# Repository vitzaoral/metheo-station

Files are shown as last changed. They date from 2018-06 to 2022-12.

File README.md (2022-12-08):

# Solar powered meteo station with ESP8266 Wemos D1 Mini Pro

## 🚀 12.2022 - UPDATE TO BLYNK 2.0 🚀
Project was updated to the new version of [Blynk 2.0](https://docs.blynk.io/en/)

IoT meteo station system based on ESP8266 Wemos D1 Mini Pro. Checks temperature, humidity and pressure. Data are sent to Blynk and ThingSpeak channel (via [Webhook widget](http://docs.blynk.cc/#widgets-other-webhook)) every minute, then is used deep sleep. Project is free to use, coded in C++, created in Visual Code with [PlatfomIO IDE](http://docs.platformio.org/en/latest/ide/vscode.html).

> To build a project, you need to download all the necessary libraries and create the _settings.cpp_ file in the _src_ folder:

```c++
// Meteo station project settings
struct Settings
{
    const char *ssid = "WIFI ssid";
    const char *password = "WIFI password";
    const char *blynkAuth = "You Blynk Auth";
    const char *version = "2.0.1";
};
```

### Powering:

Wemos D1 Mini Pro is powered by NCR18650 3.7V 3400mAh Li-ion battery (with PCB protection). Battery is charged by 6V 1W solar panel via TP4056 Lithium Battery Charger Module (with protection). Between solars panels and TP4056 is need to insert Step Down Voltage Supply Module (Buck converter), which set voltage to 5V because TP4056 does not work on higher voltage than 6V. On direct sun solars panel can get more than 6 volts so charging is not working because TP4056 automatically turn off itself on higher voltage.

Output from TP4056 is connected to 5V/GND pins on Wemos D1 Mini Pro. It works even if battery has voltage about 2.7V (then is battery automatically turn of by PCB protection). There can be [more effective ways](https://github.com/z2amiller/sensorboard/blob/master/PowerSaving.md) but this solution works well. Without charging device can works about 7 days (data are sent every minute, so for example for 10 minutes limit device will work about one month - it's depend on temperature too). Device checks battery voltage via A0 pin and sent it to the Blynk.

Solar power is monitoring by the INA219 sensor.

### OTA - Over the Air update:

Meteo station support firmware updates over internet via [Blynk](https://docs.blynk.io/en/getting-started/updating-devices-firmwares-ota)

### Currents list:

- [Wemos D1 Mini Pro with antenna](https://www.aliexpress.com/item/WEMOS-D1-Mini-Pro-16M-Bytes-External-Antenna-Connector-ESP8266-WIFI-IoT-Board/32747247131.html)
- [TP4056 Lithium Battery Charger Module Charging Board](https://www.aliexpress.com/item/Automatic-Protection-2PCS-Micro-USB-5V-1A-18650-TP4056-Lithium-Battery-Charger-Module-Charging-Board-With/32216803000.html)
- [6V 1W solar panel](https://www.aliexpress.com/item/BUHESHUI-6V-1000mA-6W-Mini-Monocrystalline-PET-Solar-Panel-Small-Solar-Cell-Battery-Bicycle-Sharing-Share/32832618716.html)
- [NCR18650B 3400mah Rechargeable battery 3.7V with PCB](https://www.aliexpress.com/item/2-PCS-lot-New-Protected-Original-Rechargeable-battery-18650-NCR18650B-3400mah-with-PCB-3-7V-Free/32628168837.html)
- [18650 Power Battery Storage Case Plastic Box Holder](https://www.aliexpress.com/item/1pcs-18650-Power-Battery-Storage-Case-Plastic-Box-Holder-With-Leads-Oct24/32756928086.html)
- [5819 1A 40V SCHOTTKY DIODE](https://www.aliexpress.com/item/50Pcs-1N5819-5819-1A-40V-SCHOTTKY-DIODE-NEW/32216810320.html)
- [DC-DC 12-24V To 5V 3A Step Down Power Supply Module Voltage](https://www.aliexpress.com/item/5Pcs-TL081-TL081CP-TI-IC-JFET-Input-Operational-Amplifiers-DIP-8-NEW-AL/32629679397.html)
- [INA219 High Side DC Current Sensor Breakout power monitoring sensor](https://www.aliexpress.com/item/INA219-I2C-interface-High-Side-DC-Current-Sensor-Breakout-power-monitoring-sensor-module/32676454542.html)
- [Prototype Paper PCB](https://www.aliexpress.com/item/Hot-Free-shipping-1Pcs-5-7-PCB-5x7-PCB-5cm-7cm-DIY-Prototype-Paper-PCB-Universal/32774676055.html)
- [Waterproof Plastic Electronic Project Box](https://www.aliexpress.com/item/115x90x55mm-Waterproof-Plastic-Electronic-Project-Box-Enclosure-Cover-CASE-L057-New-hot/32824079176.html)
- [Plastic humidity sensor project box](https://www.aliexpress.com/item/szomk-plastic-humidity-sensor-project-box-2-pcs-84-27-16mm-diy-wall-mounting-plastic-junction/32586666805.htmll)

### Schema:

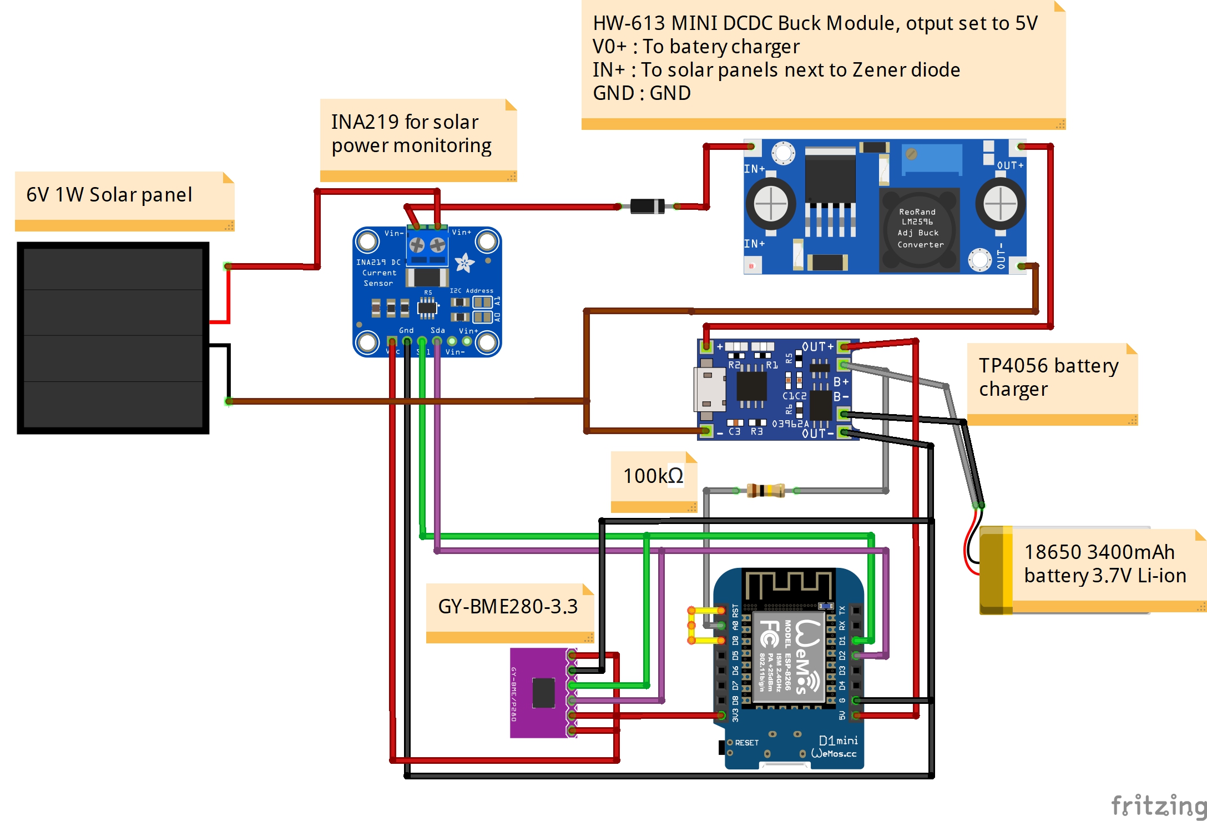
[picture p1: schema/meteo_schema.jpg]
Schema


### PCB circuit:

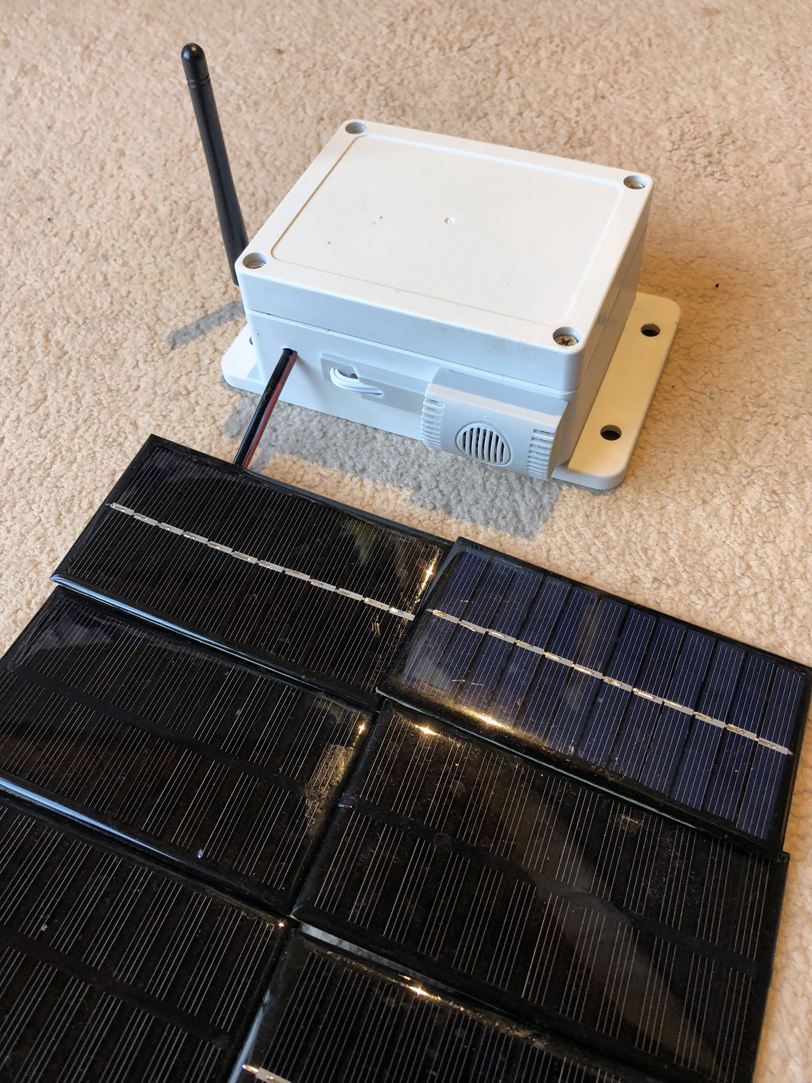
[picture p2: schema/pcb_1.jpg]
PCB 1


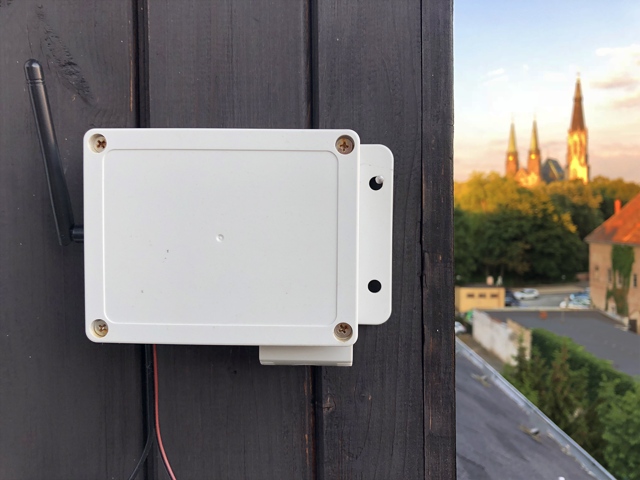
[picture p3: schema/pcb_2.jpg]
PCB 2


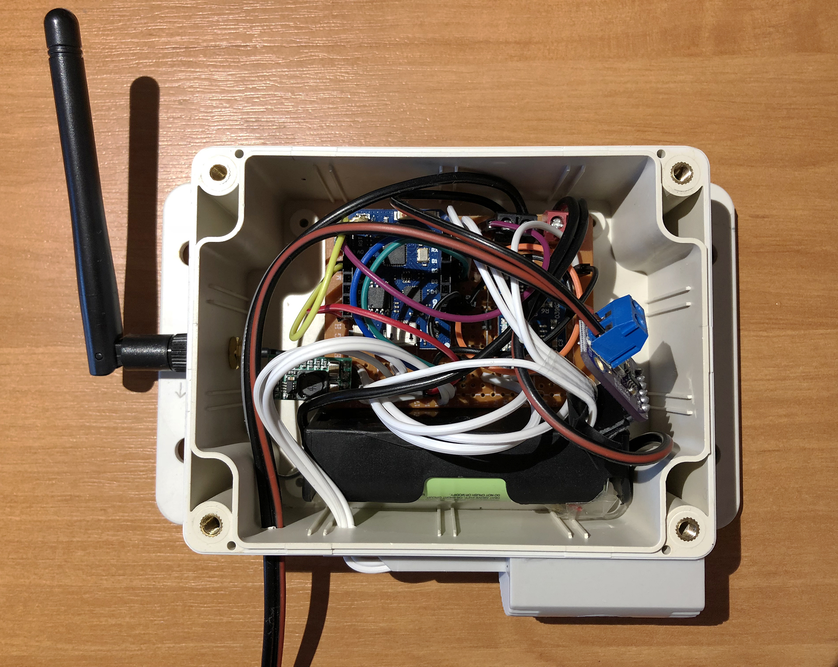
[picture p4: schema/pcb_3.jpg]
PCB 3


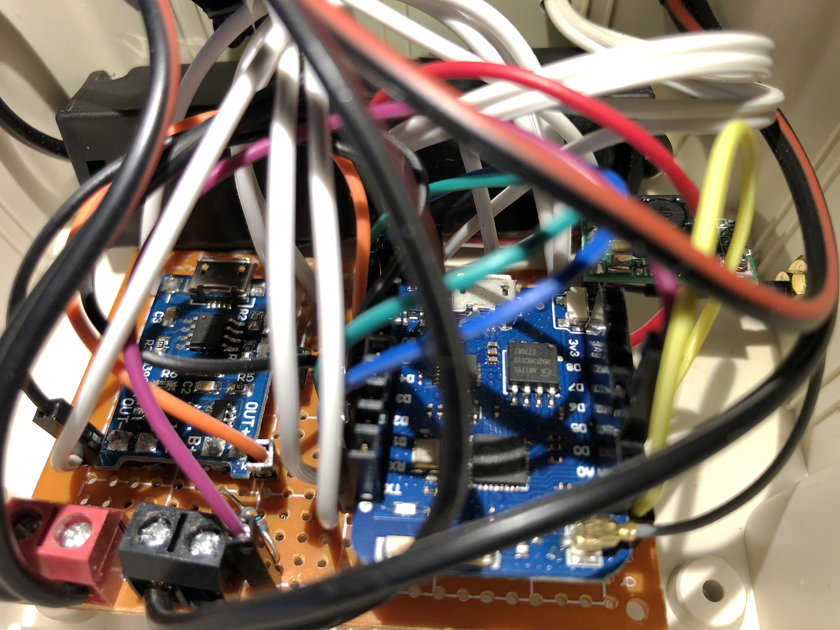
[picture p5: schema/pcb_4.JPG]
PCB 4


### Blynk:

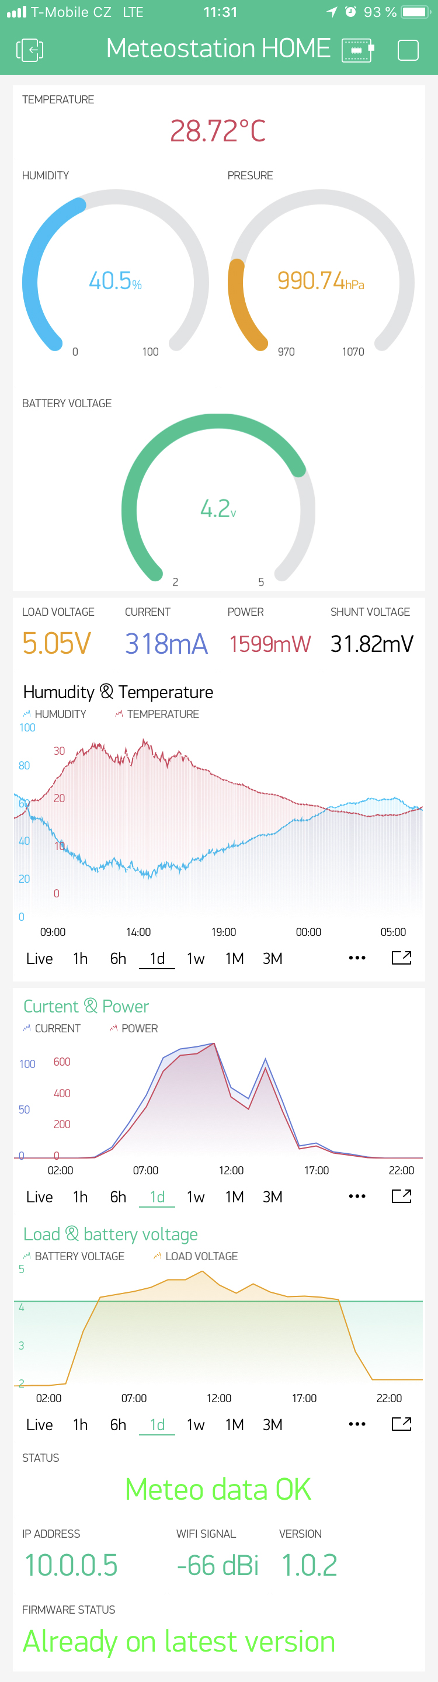
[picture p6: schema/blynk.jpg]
Blynk project


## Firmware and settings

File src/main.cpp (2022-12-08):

#include <Arduino.h>
#include <MetheoData.h>
#include <PowerController.h>
#include <InternetConnection.h>

MetheoData metheoData;
InternetConnection connection;
PowerController powerController;

// Deep sleep interval in minutes
const int deepSleepInterval = 2;

// Connections to APIs are OK
bool apisAreConnected = false;

void initializeInternetConnection()
{
    apisAreConnected = connection.initializeBlynk();
}

void deepSleep()
{
    Serial.println("Good night");
    ESP.deepSleep(deepSleepInterval * 1000000 * 60);
}

// Set up environment before loop
void setup()
{
    Serial.begin(115200);
    Serial.println("Start initialize WiFi connection");
    initializeInternetConnection();
}

// Excecute code in forever loop
void loop()
{
    if (apisAreConnected)
    {
        metheoData.setData();
        powerController.setData();

        if (metheoData.dataAreValid())
        {
            connection.sendDataToBlynk(metheoData, powerController, true);
        }
        else
        {
            Serial.println("MetheoData are invalid");
            connection.sendDataToBlynk(metheoData, powerController, false);
        }
        connection.runBlynk();
    }
    else
    {
        Serial.println("No connection to apis");
    }

    deepSleep();
}

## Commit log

2018-01-13 Added metheo library for sensor data
2018-02-20 Remove BMP085 sensor, new BMP280 sensor instead
2018-03-06 Added battery voltage monitoring
    [meteo_schema.fzz]
2018-03-14 Wemos D1 Mini Pro support
    [meteo_schema.fzz]
2018-04-15 Send data even if the sensor gets bad data. Set status to Blynk.
2018-05-09 Schema with DCDC buck module
    [meteo_schema.fzz]
2018-08-15 Data to ThingSpeak are sent via Blynk Webhooks, not directly from device.
2018-12-22 New meteo sensor, better Blynk connection
